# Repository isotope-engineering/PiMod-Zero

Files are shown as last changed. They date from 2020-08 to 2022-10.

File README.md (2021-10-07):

# PiMod Zero

The PiMod Zero brings old tech back to life by allowing a Raspberry Pi Zero to display color or B&W video—and play audio—on vintage televisions. It provides a super-compact way to watch old movies, play retro games, present digital art, or navigate your operating system using any television that receives standard NTSC broadcasts on VHF channels 2 and 3 (55.25 MHz and 61.25 MHz).

In the past, you would have needed a cumbersome RF modulator box to adapt the HDMI signal from a Pi Zero. Now, with this convenient HAT snapped on top of your Pi Zero, no additional dongles are required. In fact, once the Pi is powered up, the only other cable you need is a piece of coax to connect the PiMod Zero to your TV.



## Features
- Supports color and B&W video
- Supports audio
- Small form factor
- No external power supply
- Low power
- Open Source

## Tech Specs
- Operating frequency: VHF channels 2 and 3 (55.25 MHz and 61.25 MHz)
- Broadcast format: NTSC
- Supply voltage: 5V
- RF output power: 0.005 mW
- Impedance: 75 Ω
- Power draw: 100 mW 

## Getting Started
Check out the [Setup directory](/setup).

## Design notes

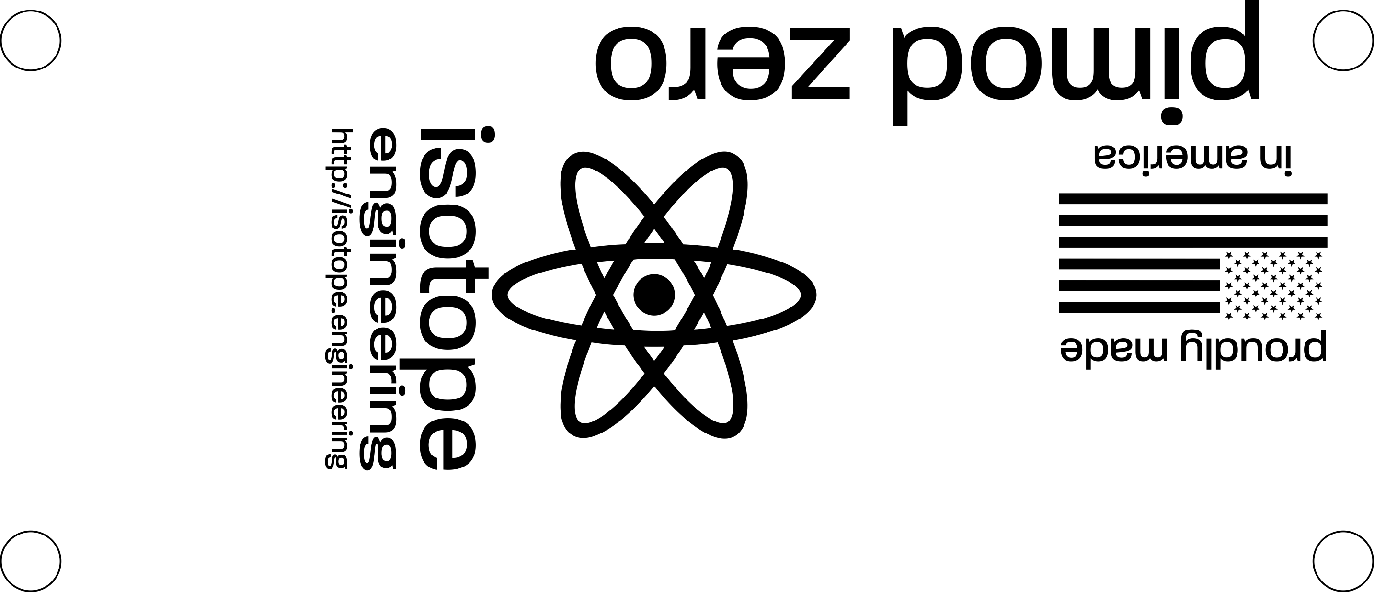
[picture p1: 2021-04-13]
hardware/artwork/back.ss.png

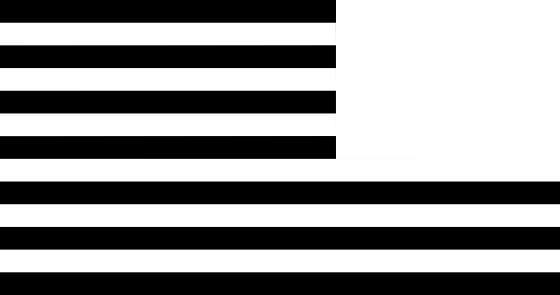
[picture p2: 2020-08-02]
hardware/artwork/back.mask.png

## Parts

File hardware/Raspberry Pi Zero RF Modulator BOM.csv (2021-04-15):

Identifier | Part Description/ Value | Package | PN | Source | Quantity | Unit Cost
U1 | RF Modulator IC | SOIC-8 | NJM2519A | Mouser | 1 | $1.05
X1 | SAW Resonator | F88SM | F88SM | TransparentC | 1 | $3.50
C1 | 6 pF, 50V, +/-0.5 pF | 0805/2012 | 0805N6R0D500CT | Mouser | 1 | $0.10
C2 | 100 pF, 100V, 5% | 0805/2012 | C0805C101J1GAC | Mouser | 1 | $0.10
C3, C12 | 1 nF, 100V, 10% | 0805/2012 | C0805C102K1HACTU | Mouser | 2 | $0.12
C4, C5 | 24 pF, 250V, 5% | 0805/2012 | GRM21A5C2E240JW01D | Mouser | 2 | $0.37
C6, C7, C8, C13 | 0.1 uF, 50V, 10% | 0805/2012 | 08055C104KAT2A | Mouser | 4 | $0.10
C9, C10 | 1 uF, 16V, 10% | 0805/2012 | CL21B105KOFNNNG | Mouser | 2 | $0.10
C11 | 1 uF, 50V, 10%, P | 0805/2012 | T491A105K050AT | Mouser | 1 | $0.85
C14 | 360 pF, 100V, 10% | 0805/2012 | 08051C361KAT2A | Mouser | 1 | $0.28
C15 | 68 pF, 100V, 1% | 0805/2012 | VJ0805A680FXBPW1BC | Mouser | 1 | $0.35
C16, C18 | 10 uF, 25V, 10% | 0805/2012 | TMK212BBJ106MGHT | Mouser | 2 | $0.30
C17, C19 | 33 nF, 100V, 10% | 0805/2012 | C0805C333K2RECAUTO | Mouser | 2 | $0.30
L1 | 133 nH, 3A | Wurth 744918213 | 744918213 | Mouser | 1 | $1.16
L2 | 18 uH (Tunable) | Coilcraft SLOT-7 | 7M3-183 | Coilcraft | 1 | $3.95
R1, R5 | 470 Ω, 0.125W, 5% | 0805/2012 | RC0805JR-07470RP | Mouser | 2 | $0.23
R2, R4 | 75 Ω 0.5W, 0.5% | 0805/2012 | ERJ-P06D75R0V | Mouser | 2 | $0.27
R3 | 510 Ω, .25W, 5% | 0805/2012 | ERJ-T06J511V | Mouser | 1 | $0.32
R6 | 220 Ω, .125W, 1% | 0805/2012 | CRCW0805220RFKEBC | Mouser | 1 | $0.16
R7 | 2 kΩ, .125W, 1% | 0805/2012 | CRCW08052K00FKEBC | Mouser | 1 | $0.16
R8 | 30 kΩ, .125W, 5% | 0805/2012 | CR0805-JW-303ELF | Mouser | 1 | $0.10
R9 | EMPTY | 0805/2012 |  |  | 0 | $0.00
R10, R13 | 270 Ω, .4W, 1% | 0805/2012 | RCS0805270RFKEA | Mouser | 2 | $0.25
R11, R14 | 10 kΩ, .5W, 1% | 0805/2012 | CHP0805-FX-1002ELF | Mouser | 2 | $0.40
R12, R15 | 150 Ω, .25W, 5% | 0805/2012 | ERJ-T06J151V | Mouser | 2 | $0.22
SW1 | SPDT | PCM12 | MSS3-V-T/R | Mouser | 1 | $0.74
J1 | 40 Pin Header | 2x20_P2.54 | 2222 | Mouser | 1 | $1.50
J2 | 2 Pin Header | 1x02_P2.54 | 90147-1102 | Mouser | 1 | $0.73
J3 | Coax Connector |  | 531-40101 | Mouser | 1 | $2.02

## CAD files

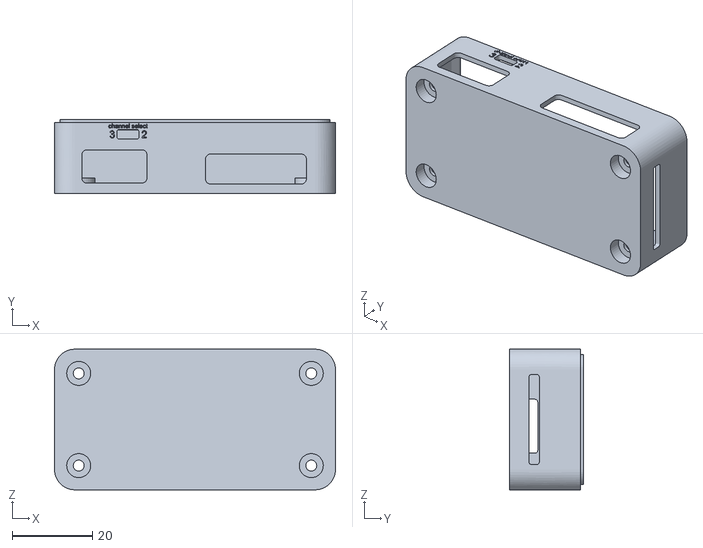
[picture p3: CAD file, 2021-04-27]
hardware/case/PiMod Zero Case - Bottom v17.stl
70.1 x 18.3 x 35.1

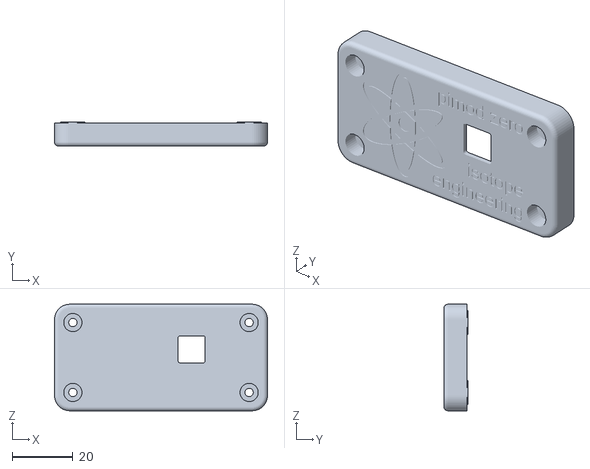
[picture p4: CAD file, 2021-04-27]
hardware/case/PiMod Zero Case - Top v17.stl
70.1 x 7.92 x 35.1

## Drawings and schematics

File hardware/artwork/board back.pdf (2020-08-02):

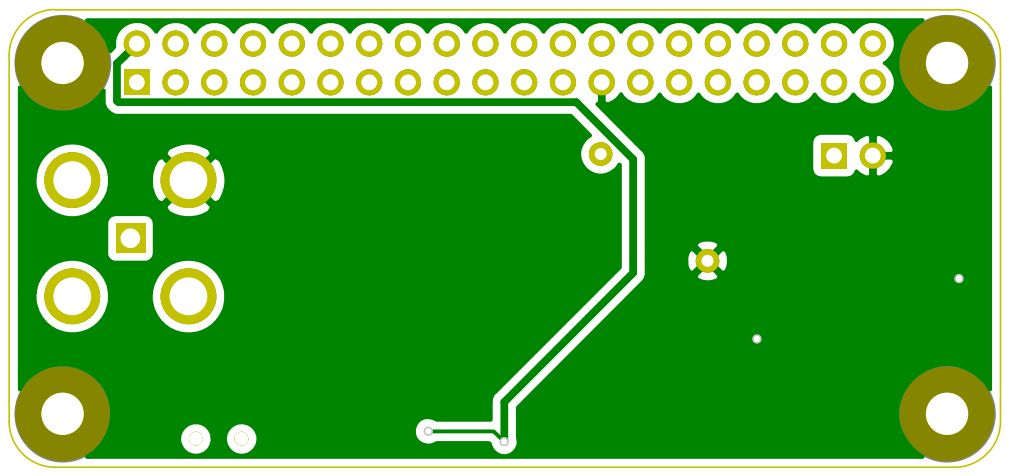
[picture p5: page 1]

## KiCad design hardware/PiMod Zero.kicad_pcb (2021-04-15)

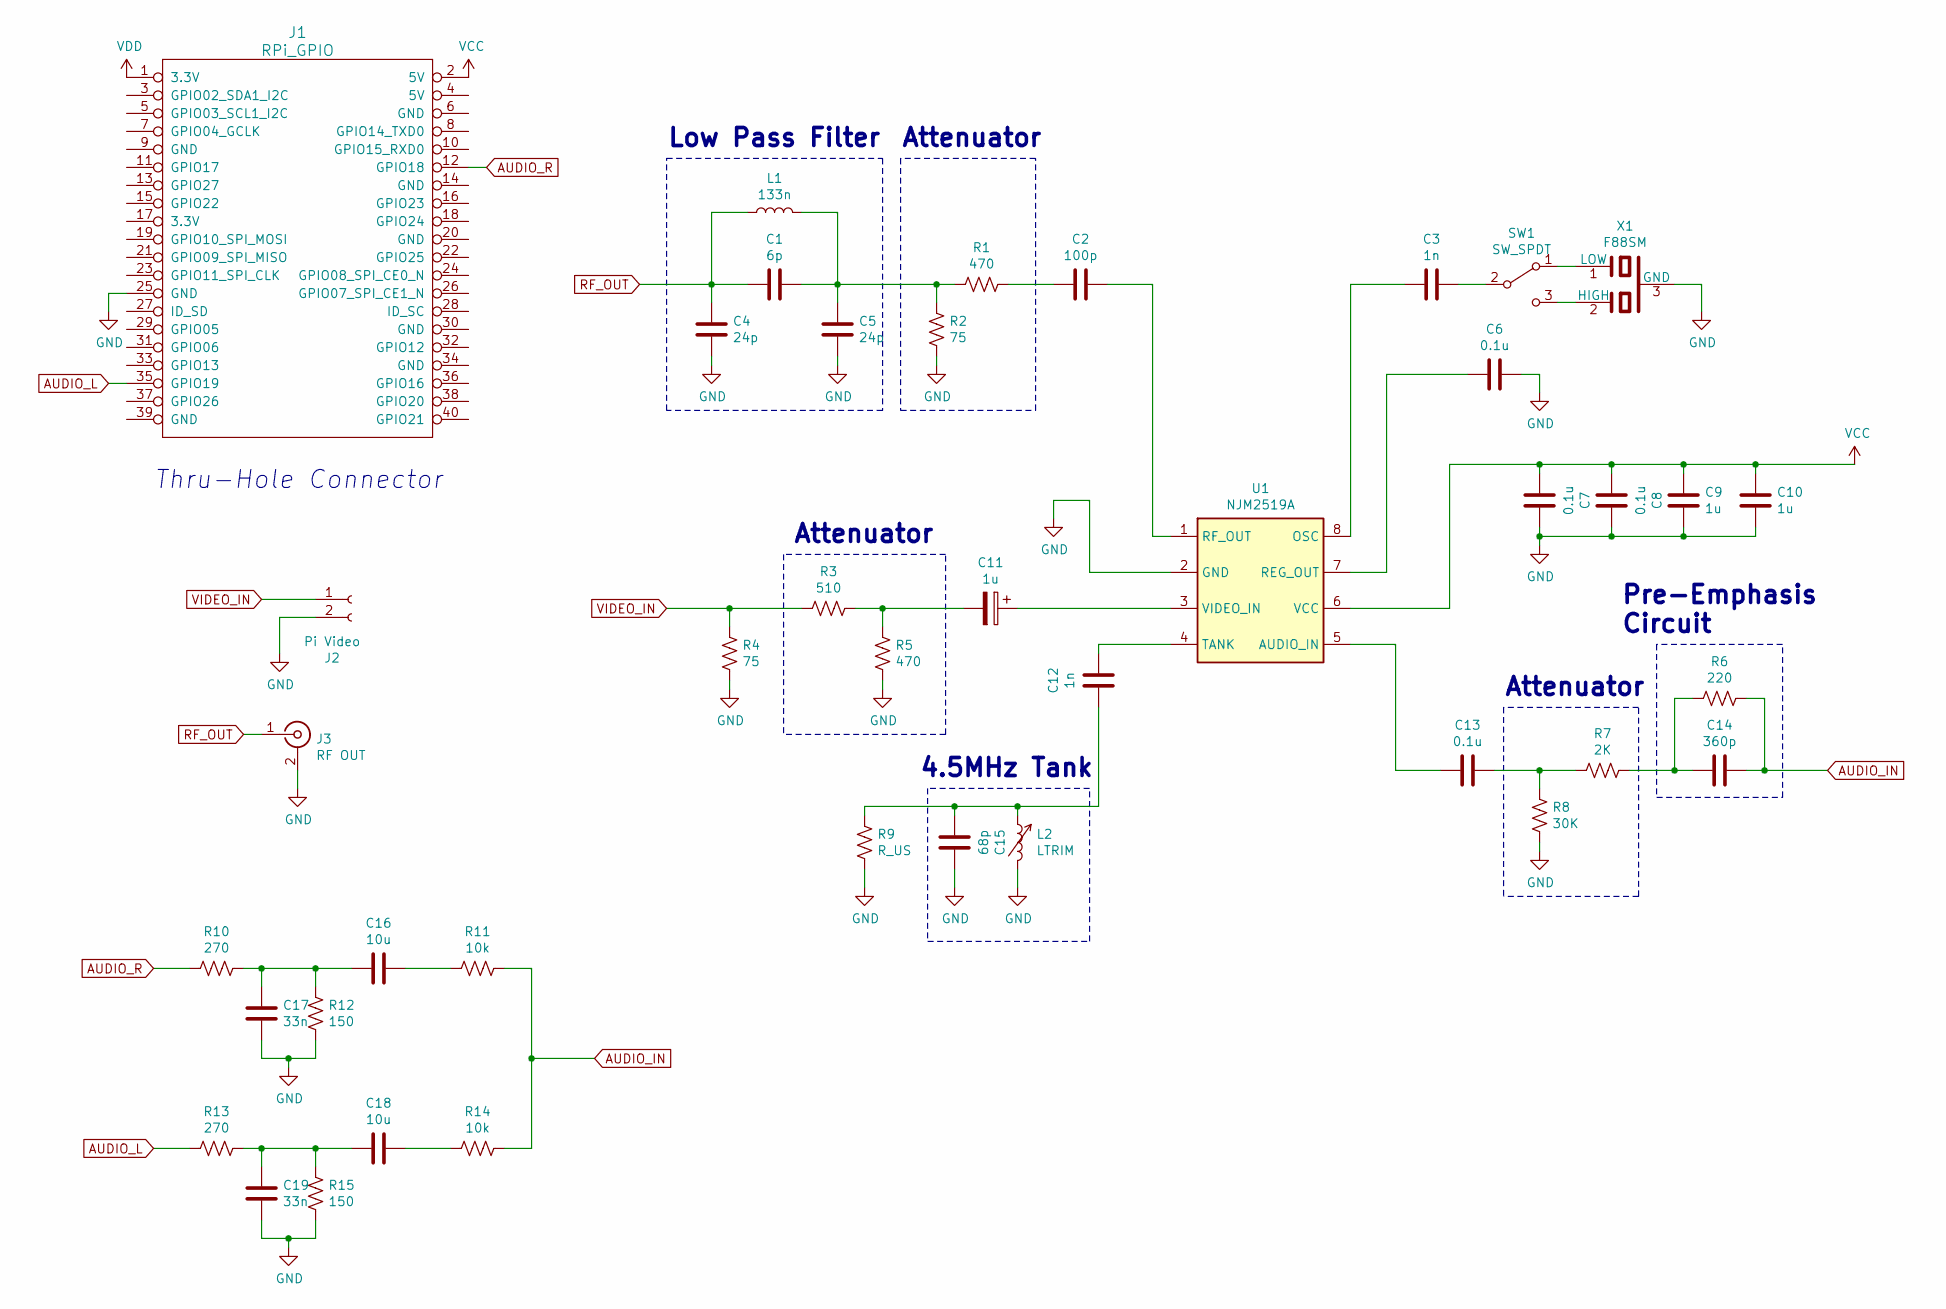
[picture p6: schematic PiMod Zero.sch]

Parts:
C1: 6p; C_0805_2012Metric; Voltage 50V; Tolerance 10%
C2: 100p; C_0805_2012Metric; Voltage 50V; Tolerance 10%
C3: 1n; C_0805_2012Metric; Voltage 50V; Tolerance 10%
C4, C5: 24p; C_0805_2012Metric; Voltage 50V; Tolerance 10%
C6, C7, C8, C13: 0.1u; C_0805_2012Metric; Voltage 50V; Tolerance 10%
C9, C10: 1u; C_0805_2012Metric; Voltage 50V; Tolerance 10%
C11: 1u; C_1206_3216Metric; Voltage 50V; Tolerance 10%
C12: 1n; C_0805_2012Metric; Voltage 50; Tolerance 10%
C14: 360p; C_0805_2012Metric; Voltage 50V; Tolerance 10%
C15: 68p; C_0805_2012Metric; Voltage 50V; Tolerance 1%
C16, C18: 10u; C_0805_2012Metric; Voltage 50V; Tolerance 10%
C17, C19: 33n; C_0805_2012Metric; Voltage 50V; Tolerance 10%
J1: RPi_GPIO; PinHeader_2x20_P2.54mm_Vertical; Part Number Adafruit 2222
J2: Pi Video; PinHeader_1x02_P2.54mm_Vertical; Part Number 90147-1102
J3: RF OUT; 531400473; Part Number 73330-0030
L1: 133n; Wurth_WE_Inductor_744918213; Tolerance 5%; Part Number 744918213
L2: LTRIM; Coilcraft Slot 7 Inductor; Part Number Coilcraft 7M3-183
R1, R5: 470; R_0805_2012Metric; Tolerance 5%
R2, R4: 75; R_0805_2012Metric; Tolerance 0.5%
R3: 510; R_0805_2012Metric; Tolerance 5%
R6: 220; R_0805_2012Metric; Tolerance 5%
R7: 2K; R_0805_2012Metric; Tolerance 5%
R8: 30K; R_0805_2012Metric; Tolerance 5%
R9: R_US; R_0805_2012Metric
R10, R13: 270; R_0805_2012Metric; Tolerance 5%
R11, R14: 10k; R_0805_2012Metric; Tolerance 5%
R12, R15: 150; R_0805_2012Metric; Tolerance 5%
SW1: SW_SPDT; SW_SPDT_PCM12; Part Number MSS3-V-T/R
U1: NJM2519A; SOIC-8_5.23x5.23mm_P1.27mm; Part Number NJM2519A
X1: F88SM; Part Number F88SM

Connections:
AUDIO_IN: C14.1, R6.1, R11.1, R14.1
AUDIO_L: J1.35 (GPIO19), R13.2
AUDIO_R: J1.12 (GPIO18), R10.2
unnamed: C1.1, C5.1, L1.2, R1.2, R2.1
unnamed: C2.1, U1.1 (RF_OUT)
unnamed: C2.2, R1.1
unnamed: C3.1, SW1.2 (B)
unnamed: C3.2, U1.8 (OSC)
unnamed: C6.2, U1.7 (REG_OUT)
unnamed: C11.1, U1.3 (VIDEO_IN)
unnamed: C11.2, R3.1, R5.1
unnamed: C12.1, U1.4 (TANK)
unnamed: C12.2, C15.2, L2.1, R9.1
unnamed: C13.1, R7.2, R8.1
unnamed: C13.2, U1.5 (AUDIO_IN)
unnamed: C14.2, R6.2, R7.1
unnamed: C16.1, R11.2
unnamed: C16.2, C17.1, R10.1, R12.1
unnamed: C18.1, R14.2
unnamed: C18.2, C19.1, R13.1, R15.1
unnamed: SW1.1 (A), X1.1 (LOW)
unnamed: SW1.3 (C), X1.2 (HIGH)
VCC: C7.2, C8.2, C9.2, C10.2, J1.2 (5V), U1.6 (VCC)
VDD: J1.1 (3.3V)
VIDEO_IN: J2.1, R3.2, R4.1

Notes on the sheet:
Low Pass Filter
Attenuator
Pre-Emphasis Circuit
4.5MHz Tank
Thru-Hole Connector

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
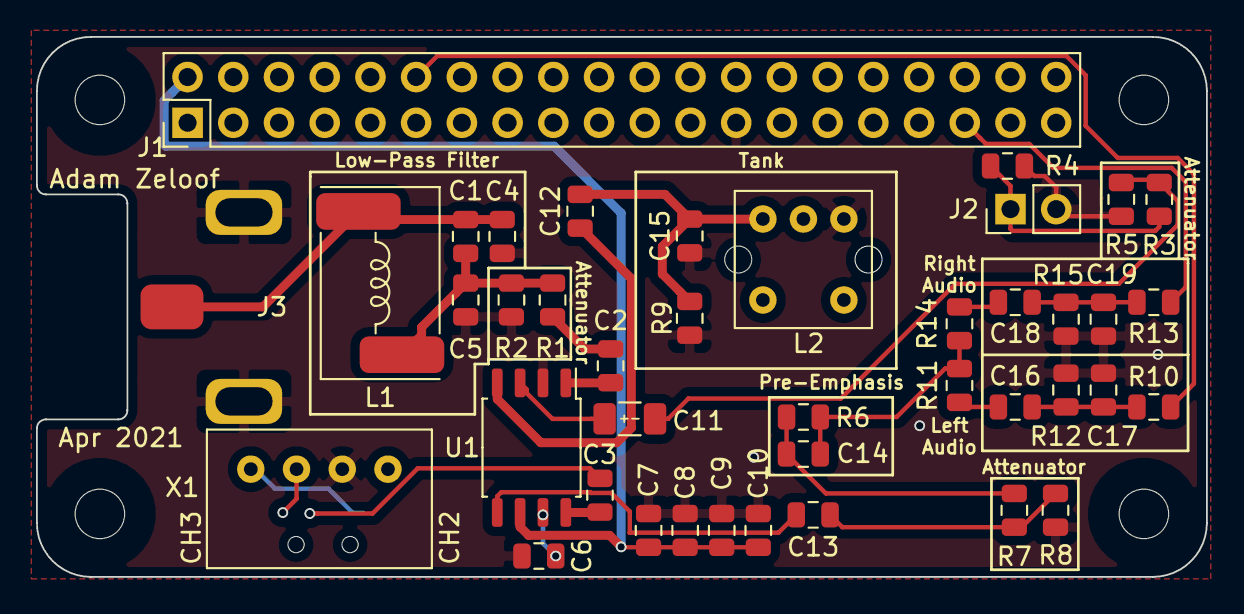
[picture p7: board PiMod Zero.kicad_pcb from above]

Board: 2 copper layers, 65.0 x 30.0 mm, 42 parts (1 on the bottom side), 26 nets.

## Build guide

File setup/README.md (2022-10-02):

# Setup Instructions

## Hardware Assembly

First things first, you'll have to solder the headers (J1 and J2) to their respective locations on the PiMod Zero, and solder their counterparts to your Raspberry Pi Zero. Once that is done, you can proceed to software setup.

## Software Setup

- Flash MicroSD Card with fresh Raspbian image
- Install shield and power up, connect to TV
- Video should automatically display on the TV
- Turn TV volume up, you should hear a buzzing noise
- Tune the inductor on the PiMod until the buzzing is silent
- ssh into pi
- `sudo apt install pulseaudio`
- Either run `sudo PiMod-Audio-Setup.sh`, or add the following lines to /boot/config.txt:
```
dtoverlay=pwm-2chan,pin=18,func=2,pin2=19,func2=2
dtoverlay=audremap,enable_jack=on
```
- Reboot
- `wget https://www2.cs.uic.edu/~i101/SoundFiles/CantinaBand60.wav`
- `aplay CantinaBand60.wav`
- You should be able to hear the music! Fine tune the inductor to achieve best sound quality

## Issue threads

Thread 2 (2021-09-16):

Whats the power output of the pimod zero?

devicemodder, 2021-09-16:
I'd like to hook an antenna up to the output so I can use the pi with multiple TV sets. What's the output power level from the cable connector, and what would rhe range be with a standard extendable antenna connected?

Closed 2021-09-16.

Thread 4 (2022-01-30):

Setup Issues

TheSuperN3rd, 2022-01-30:
Ok, so I finished soldering everything and I tested the connections to my TV, but the screen is black and white instead of color on my color tv, and after the 'Welcome to Raspbian' screen, it just stays blank. I can VNC into the pi zero and the desktop shows up remotely on my laptop, but not on the television. Is there something wrong with the physical connections? Or is it software related? I'd appreciate any feedback

TheSuperN3rd, 2022-01-30:
Another thing that just happened, I went to fine tune the inductor and the interior threaded piece shattered as I very gently turned it with a flathead screwdriver. Would there be any way to get a replacement inductor part to resolder to the pHAT?

azzeloof, 2022-01-31:
Are there any other displays plugged in? If an HDMI display is connected on boot it can disable composite output. You can take a look at the settings in raspi-config as well to see what the output mode is set to.
As for the B&W/color, are you using an NTSC TV? If its PAL, that could be an issue. Another possible cause is that the tuning inductor is not set properly. Which brings us to the last point- the inductor is a [Coilcraft 7M3-183](https://www.coilcraft.com/en-us/products/rf/tunable-rf-inductors/vertical-mount/slot7/7m3-183/). You can grab a replacement form their website, or you may be able to email/call and just ask for a replacement core, which can be fully unscrewed and replaced. The "set" position is usually when the top of the core protrudes ~1/8"

TheSuperN3rd, 2022-01-31:
Nope, I just have the one coax cable going from the Pi to the TV. The TV is an NTSC Hitachi color TV, I've used it for RF broadcasting before until my blonder tongue died. The weird thing is I get a picture at startup but then the desktop doesn't display on screen, but I can VNC into it on my laptop and see it just fine.

 Thanks for the info on the inductor, I'll see about ordering a replacement or email about a replacement core. The inductor was screwed all the way in and when I went to unscrew the core it just shattered :/ I'll attach am image ir a link to an image in a little bit

azzeloof, 2022-01-31:
Hmm, the lack of color is weird. Like I said it may be fixed by tuning the inductor- can you turn it by hand, or is the broken part fully in the thread?
Also, if there's nothing in the video output settings of raspi-config, you could try and add this to your pi's config.txt:
`enable_tvout=1`

TheSuperN3rd, 2022-02-01:
Ok, partial success! I now have color output! I think when the core shattered i site the inductor, there was a small piece lodged inside interfering with the signal. After completely unscrewing the core, the display changed to color, and stayed that way after partially reinserting the core so I didn't lose it.

With that fixed, I'm going to work on the software end of things to see if I can get a full display, rather than just the welcome splash screen.

TheSuperN3rd, 2022-02-02:
Video success! The problem was the AMD Freesync throwing the video detection off. I changed the driver from 'kms' to fkms' in the config.txt
dtoverlay=vc4-fkms-v3d

I'm still having trouble with audio, for some reason I still can't run the script even under the root with the 'sudo su' command. I've tried 'sudo PiMod-Audio-Setup.sh' and './PiMod-Audio-Setup.sh' to no avail. I can't figure out for the life of me how to run the script, even though I', in the directory folder of the cloned repository!

azzeloof, 2022-02-02:
Great! Nice work, that's a fantastic find. I would not have suspected Freesync, but I'm glad you were able to work out a solution.
Have you tried making the script executable? `chmod +x PiMod-Audio-Setup.sh`
If that doesn't work, the getting started guide lists the commands that the script automates, you could run them manually (there are only a couple)

TheSuperN3rd, 2022-02-05:
Total success!! Audio and Video functions well!
I believe the command that ran the shell was 'sudo sh PiMod-Audio-Setup.sh" after making it executable with the chmod command.

azzeloof, 2022-02-06:
Great work! Thanks for reporting back & following up.

Closed 2022-02-05.

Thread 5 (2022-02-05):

Not an issue l, but a question

TheSuperN3rd, 2022-02-05:
Not that I have everything functional, I have a question about RF output. Is there a way to increase the output to use a pair of rabbit ear antennas effectively? I have a pair that I've played around with and the range is near non existent. I have a color watchman that I tested the range with and I had to be almost touching the antenna in order to get a clear picture. I have an old RCA antenna amplifier, but that just made the picture worse since it's just a weak signal to begin with. Would appreciate any input!

azzeloof, 2022-02-06:
Ha! Great question. Short answer is no, there isn't an easy way to increase the output, but it would theoretically be possible to run it into an appropriate RF amplifier to achieve a lower-power signal. This is untested and unsupported, of course, and I'd advise you to check with local laws to make sure that you're not going over any power limits or stepping on any reserved frequencies.

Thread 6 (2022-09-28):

No video out

haxorthematrix, 2022-09-28:
I just received my PiMod-Zero a few days ago, and I'm having some issues, specifically, I see no desktop or video out but sound works just fine.  Fresh Raspberry Pi OS with desktop install (Kernel version: 5.15 Debian version: 11 (bullseye)) on a Raspberry Pi Zero W 1.1.  config.txt is attached - I've manually added the two required lines in the setup documentation, as well as verifying  with raspi-config that composite output is enabled and even added `enable_tvout=1` as well.  I also bounced back and forth between `dtoverlay=vc4-fkms-v3d` and `dtoverlay=vc4-kms-v3d` and no change was observed.  Yes, a reboot/power off was performed between each change.  No HDMI was connected during testing.

I've tested on two different TVs, one known to be working (the other unknown), through a 75ohm (coax) to 300ohm (dual lead) adapter.  Sound works, but no video on either channel 2 or 3, but I'm unsure how to switch on the PiMod-Zero if needed.

Changed to a Raspberry Pi 2 model B v1.1, to same effect.  I may not have changed all of the config.txt output there, as it was early on in my testing.

Figuring that my 75-300ohm adapter may be bad, I switched to a known working TV that could take direct coax input.  The TV could sense that there was some signal on channel 2 (but not 3), audio played, but still no video/desktop shown on the TV.

Any help here is appreciated.  I'm assuming J2 is for switching between channel 2 and 3, so I will populate that today and see if there are any changes.

[config.txt](https://github.com/isotope-engineering/PiMod-Zero/files/9665594/config.txt)

haxorthematrix, 2022-09-28:
....and the biggest Facepalm moment of them all:

If you want composite video to work, one needs to populate JP2 and the unpopulated TV header on the Pi Zero.

I did that and it works!  Happy to do a pull request to make the instructions more clear if you think it is warranted.

azzeloof, 2022-10-02:
I'm glad you were able to get it working! I just made a slight change to [the instructions](https://github.com/isotope-engineering/PiMod-Zero/tree/master/setup) that I hope makes the issue more clear, but if you've got any further suggestions I'd love to hear them!

Closed 2022-09-28.

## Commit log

2020-08-02 Initial Commit
    Migrated from old repo
    [pi_zero_video_modulator.sch]
2020-08-07 Added PLL to schematic
    [pi_zero_video_modulator.sch]
2020-08-08 Connected Clocks in Schematic
    [pi_zero_video_modulator.sch]
2021-04-04 Changed board profile and F connector
    [pi_zero_video_modulator-B_Cu.gbl, pi_zero_video_modulator-B_Fab.gbr, pi_zero_video_modulator-B_Mask.gbs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]
2021-04-13 Documentation Update
    [PiMod Zero.kicad_pcb, PiMod Zero.sch, pi_zero_video_modulator.kicad_pcb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]
2021-04-14 Updated 3D models
    [PiMod Zero.kicad_pcb]
2021-04-15 Added BOM
    [PiMod Zero.kicad_pcb, Raspberry Pi Zero RF Modulator BOM.csv]
2021-04-27 Added 3D Printed Case
    [PiMod Zero Case - Bottom v17.stl, PiMod Zero Case - Top v17.stl]
